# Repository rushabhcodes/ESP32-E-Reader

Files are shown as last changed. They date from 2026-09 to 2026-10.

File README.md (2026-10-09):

# ESP32 E-Reader Rev. B

A four-layer, battery-powered e-reader PCB built around the ESP32-C3 and a
high-resolution four-color e-paper display. This repository contains the
[tscircuit](https://tscircuit.com/) implementation of the Rev. B hardware,
including the schematic, PCB layout, component data, and fabrication export
workflow.

## At a glance

| Specification | Current design |
| --- | --- |
| Enclosure outside | 68.0 × 111.0 × **16.8 mm**; prototype CAD, not a measured print |
| PCB | 62.5 × 95.08 × 1.6 mm; four copper layers |
| Display | EastRising ER-EPD3.97-1RY, raw display only; 480 × 800, four colors, no frontlight |
| Processor | ESP32-C3-WROOM-02U-N4; 4 MB flash, Wi-Fi, Bluetooth LE, external antenna |
| Storage | MicroSD over SPI |
| Battery | Protected 1-cell LiPo, 3.7 V nominal; modeled around 2000 mAh SparkFun PRT-13855 |
| Battery envelope | 49.2 × 68.8 × 5.6 mm nominal, excluding unverified lead and plug |
| USB | USB-C for charging and native ESP32-C3 USB data |
| Input | Four recessed navigation buttons, wake, reset, main power switch |

This repository is the **hardware and printable enclosure prototype**. It
does not contain e-reader firmware. Battery runtime, display cable fit, and
final printed fit have not been measured on an assembled device.

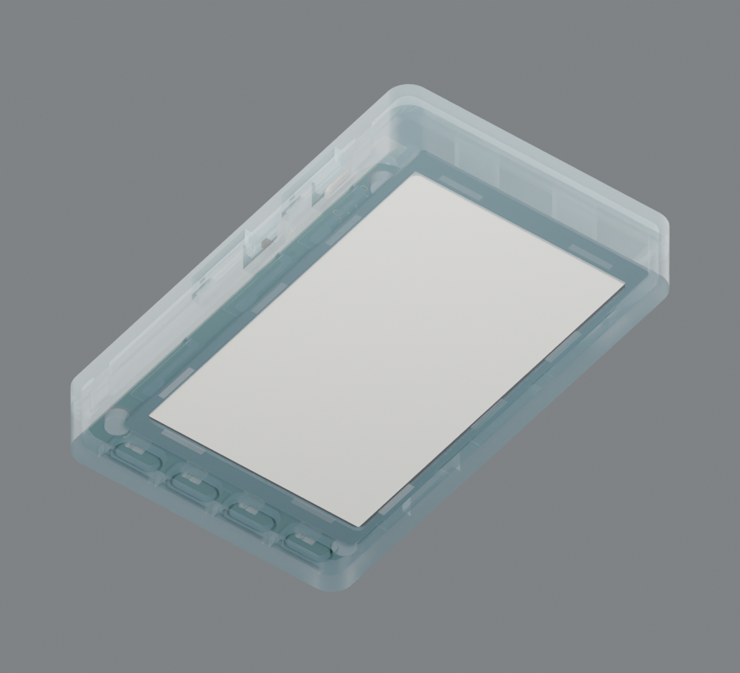
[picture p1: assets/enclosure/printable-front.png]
Front of the dimensioned e-reader print prototype


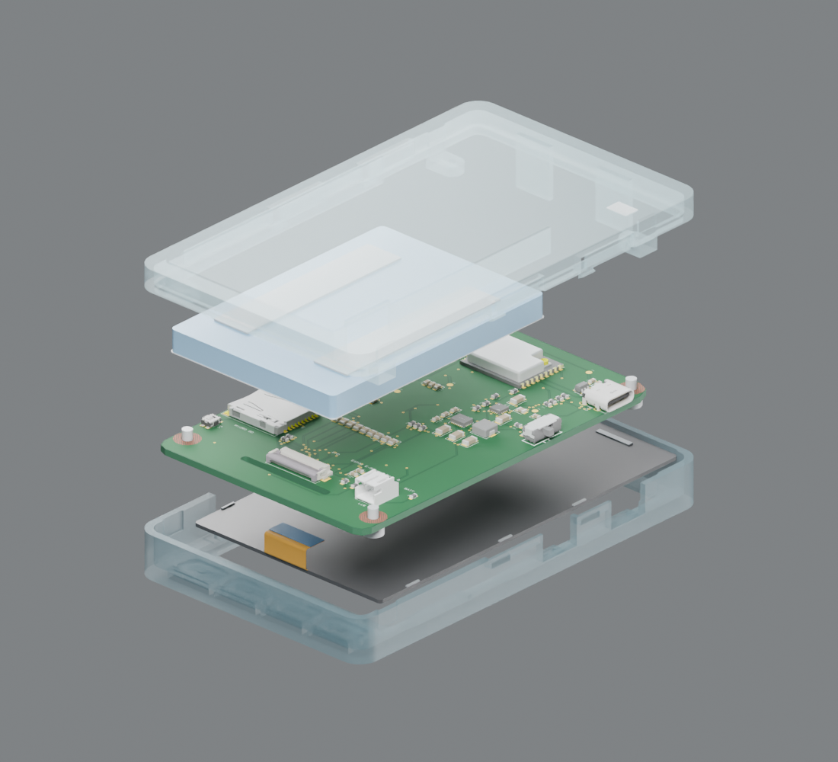
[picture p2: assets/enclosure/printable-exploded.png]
Exploded view of the screen, PCB, battery and rear cover


## Display

The selected panel is the [EastRising ER-EPD3.97-1RY](https://www.buydisplay.com/3-97-inch-quad-color-e-paper-screen-e-ink-display-480x800),
identified by the user on 6 October 2026. Its [datasheet](https://www.buydisplay.com/download/manual/ER-EPD3.97-1_Datasheet.pdf)
(Rev. 1.0, 18 August 2026) specifies an SSD2677 controller, 480 × 800 pixels,
and a 56.24 × 96.62 mm panel, matching the existing display envelope.

J2 remains the Hirose FH12-24S-0.5SH(55), with 24 positions at 0.50 mm
pitch. At the user's direction, the supplier product listing is authoritative
for connector pitch in this revision. No adapter is used. The conflicting
0.80 mm drawing is recorded as a supplier documentation discrepancy, rather
than the design basis. Connector fit remains a listing-based assumption;
contact side, stiffener thickness and cable fold still need a sample fit.

The PDF pin assignments match J2's existing functions. Pins 6 (TSCL) and
7 (TSDA) are connected to GND to give the unused sensor inputs defined low
levels, as required by page 7. Pin 8 is also low for four-wire SPI.

The display uses the same connection style as the
[Linux Game Boy Advance reference](https://tscircuit.com/ShiboSoftwareDev/linux-gameboy-advance#3d):
a folded flat ribbon entering a horizontal, bottom-contact ZIF socket.
The reader uses the [24-pin Hirose FH12](https://www.hirose.com/en/product/p/CL0586-0521-0-55)
for its e-paper pinout. Open the flip latch, insert the tail straight with its
exposed contacts facing the PCB, then close the latch.

J2 and the 26 × 2 mm rounded ribbon slot share X = 0 mm. J2 is now at
Y = −32.34 mm and the slot at Y = −38.41 mm, shortening the path from the
lower panel edge. The installed model has two 0.6 mm-radius quarter bends
and an approximately 11.316 mm centerline, within the drawing's
11.27 ± 0.30 mm extension below the glass. It passes through the slot and
shows 24 bottom-facing contacts and a nominal 0.3 mm reinforced insertion tip.
The panel remains 56.24 × 96.62 × 0.9 mm at Y = 10.5 mm, Z −4.65…−3.75 mm;
the model now subtracts J2's 0.8 mm anchor height to align with the case rebate.

The [connection dimensions](assets/enclosure/display-connection.json) and
[installed ribbon preview](assets/enclosure/display-ribbon-connection.png)
describe nominal installation geometry, not OEM flex CAD. Its 12.5 mm tip
width follows the user-selected 24-pin, 0.5 mm listing specification; it does
not reproduce the conflicting PDF's 19.6 mm, 0.8 mm tip. The delivered tail's
width, contact face, reinforcement and allowable bend radius need a physical
sample. Do not force a mismatched ribbon into the socket.

> [!IMPORTANT]
> Do not select a panel based only on the “4.2-inch” description or the 24-pin
> connector. Many e-paper panels use similar FPCs but have different pinouts,
> resolutions, controllers, dimensions, and voltage requirements. The PCB and
> firmware must match the **EastRising ER-EPD3.97-1RY** pinout.
> J2 selection uses the supplier listing's 24-pin, 0.50 mm specification.

## Hardware overview

| Function | Implementation |
| --- | --- |
| MCU | ESP32-C3-WROOM-02U-N4, 4 MB flash, Wi-Fi and Bluetooth LE |
| Display | EastRising ER-EPD3.97-1RY raw 480 × 800 four-color panel |
| Storage | MicroSD card over shared SPI |
| USB | USB-C power, native USB data, CC resistors, and USB ESD protection |
| Battery | Single-cell LiPo through a 2-pin JST-PH connector |
| Charging | BQ24074 power-path LiPo charger, 500 mA USB input limit |
| Battery protection | DW01A with FS8205A dual MOSFET |
| Logic supply | TPS63021 fixed 3.3 V buck-boost converter |
| Controls | Back, Confirm, Left, Right, Wake, Reset/Enable, and main power switch |
| Board | 62.5 × 95.08 mm, 1.6 mm thick, four copper layers |

### Parts and supplies for one prototype

| Item | Selection / requirement |
| --- | --- |
| U4 microcontroller | ESP32-C3-WROOM-02U-N4 with external U.FL antenna |
| Display | EastRising ER-EPD3.97-1RY, raw display only |
| External antenna | Taoglas FXP75.07.0045B, 45 mm cable; rear-cover adhesive mount |
| J2 display connector | Hirose FH12-24S-0.5SH(55), 24 positions at 0.5 mm pitch |
| J4 MicroSD socket | Hirose DM3AT-SF-PEJM5 |
| J1 USB-C receptacle | GCT USB4105-GF-A |
| BT1 battery header | JST S2B-PH-K-S(LF)(SN), 2-pin, 2.0 mm pitch, side entry |
| Battery | Protected 3.7 V nominal single-cell pack; modeled PRT-13855, 2000 mAh, 49.2 × 68.8 × 5.6 mm |
| Navigation switches | 4 × Alps Alpine SKRPACE010, bottom-side assembly |
| Other controls | 2 × Panasonic EVQP7C01P (S1/S2); 1 × C&K JS102011SAQN (SW7) |
| Printed parts | Two: front chassis with integral keys, screen clips and latch receivers; transparent snap-fit rear cover with PCB supports and battery guides |
| Assembly supplies | 4 M2.5 × 4 mm internal PCB screws (head ≤5 mm diameter, ≤2.5 mm high), display-border pads, 0.2 mm insulating battery liner and two 0.5 mm nonconductive adhesive strips; zero cover screws |

The [source component list and LCSC/JLCPCB mappings](design-data.ts) and the
[generated BOM](#fabrication-files) cover the remaining passives, charger,
protection devices, ESD device, and e-paper bias circuit. The USB-C body is
checked against the printable case using the local GCT manufacturer OBJ;
the antenna cable and mating plug remain unmodeled. The display fold is nominal CAD. Confirm the delivered display tail, battery plug polarity,
antenna cable path, and screw fit before assembly.

The four navigation buttons share one ESP32 ADC input through a resistor
ladder. The e-paper display and MicroSD card share the SPI clock and MOSI lines
while using independent chip-select signals. USB D+ and D− connect directly to
the ESP32-C3's native USB pins.

The four front navigation controls use the same **Alps Alpine SKRPACE010**
bottom-side tactile switch listed in the [original reader's
BOM](https://github.com/IS7V4N/ESP32_E-Reader). Each switch is 4.2 × 3.2 ×
2.5 mm, with 0.2 mm travel and 2.55 N operating force according to the
[manufacturer](https://tech.alpsalpine.com/e/products/category/tact-switch/sub/02/series/skrp/).
They sit on 14 mm centers within the 62.5 mm board width. Moving the row 4 mm
closer to the display removes 5 mm from the lower PCB edge while keeping about
2 mm between the panel outline and the button openings. Four slim key caps and independent PETG leaf arms are integral to the front
chassis. This requires bottom-side switch assembly. Each key has a nominal
0.04 mm rest gap and 0.25 mm total stroke, giving about 0.21 mm switch
compression. Force, return and print fit need a physical prototype. Check the actual
display ribbon width and fold radius against the 26 mm FPC slot before ordering
the PCB.

## Dimensioned enclosure print prototype

The redesigned Rev. E enclosure uses **two printed parts** in a
**68.0 × 111.0 × 16.8 mm** envelope, 1.2 mm (6.7%) thinner than Rev. D.
Moving the same battery toward the button end avoids stacking it over the
ESP32 module. The front chassis combines the screen
ledge, six releasable padded border clips and four independently moving keys.
The transparent rear cover combines the PCB cantilever supports, battery guides,
four integral snap leaves and two extra supports for the upper screen border.

The PCB fastens to the rear cover from its display-facing underside. The
front chassis therefore has a clear path for screen installation. Four side
snap hooks engage matching receivers in the front chassis. Recessed side
windows allow releasing them with a plastic pick. Four M2.5 screws retain
the PCB; the cover uses no screws. The selected protected
[SparkFun PRT-13855 pack](https://www.sparkfun.com/lithium-ion-battery-2ah.html)
has **49.2 × 68.8 × 5.6 mm nominal dimensions**. It bonds to the inside rear
cover with two nonconductive foam adhesive strips; a thin insulating liner
covers its PCB-facing surface. No separate battery tray needs printing.
The battery is now centered at X −6.0, Y −8.5 mm and lowered from Z 4.9 to
Z 3.7. The rear wall remains 1.2 mm thick. The screen's padded ledge, six clips
and two upper supports retain their original seating positions.
Print both Rev. E shells as a pair. The battery loads through the open upper
end of its guides and slides 6.5 mm toward the lower stop before fitting the PCB.

| Thickness contribution | mm |
| --- | ---: |
| Front outer face to PCB center | 5.8 |
| PCB center to battery base | 3.7 |
| Nominal battery thickness | 5.6 |
| Battery mounting adhesive | 0.5 |
| Rear cover | 1.2 |
| **Modeled outside thickness** | **16.8** |

The battery liner has 0.25 mm nominal clearance above the lower PCB mounting
bosses and about 0.59 mm above L1. The shifted battery's liner clears the
ESP32 module by 1.63 mm in Y. These are CAD measurements; actual pack thickness,
swelling allowance, wires and printed tolerances need a prototype check.

The actual CAD materials use alpha blending: 0.38 opacity for the front,
0.22 for the rear. The hosted viewer and native export use 0.5 opacity through
the explicit translucency flags. This lets you see the components inside. Clear PETG FDM
prints are normally translucent; the CAD appearance does not predict glass-like
clarity. The design assumes a 0.4 mm nozzle and PETG flexures. Physical fit,
clip force, key fatigue, battery retention and cable routing need a prototype.

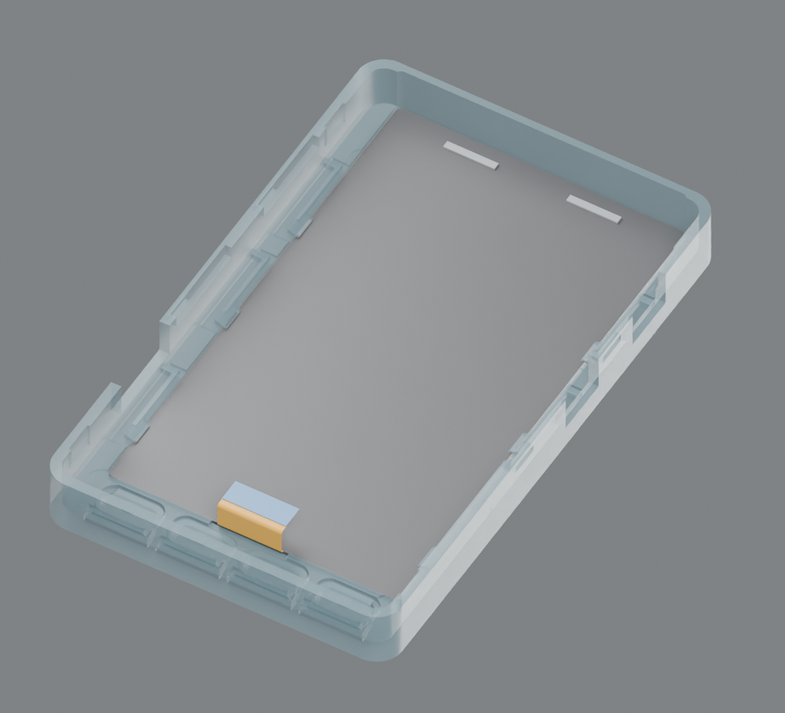
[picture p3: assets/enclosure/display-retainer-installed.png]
Display held on padded border ledges and integral side clips


The [print ZIP](assets/enclosure/esp32-reader-printable-stls.zip) contains exactly
**two bed-oriented STLs**, the [220 × 220 mm 3MF plate](assets/enclosure/reader-print-plate.3mf),
and the [print and assembly guide](assets/enclosure/PRINTING.md). Both parts
print flat, outside face on the bed. Use removable supports under the spring
leaves and projecting features, including supports that start on the model.
The open battery pocket leaves them accessible for removal.

The [component inventory](assets/enclosure/component-inventory.csv) records
PCB references, footprint sizes and model envelopes. `bun run export:assembly`
resolves the local CAD and writes `dist/index/assembly.glb`; missing OBJ/GLB
fetches fail the export. Supplier OBJ models are bundled for browser rendering.
The supplier STEP archives ([1](assets/components/supplier-step-models-1.zip), [2](assets/components/supplier-step-models-2.zip), [3](assets/components/supplier-step-models-3.zip), [4](assets/components/supplier-step-models-4.zip), [5](assets/components/supplier-step-models-5.zip)) preserve
original source models without loading large STEP duplicates in the preview.
Source URLs and hashes remain in `assets/components/sources.json`.

Four PCB mounting holes retain their original coordinates: the upper pair at
X ±27, Y 44.75 mm and the lower pair at X ±28, Y −40 mm. Each 2.7 mm hole has
a 3.2 mm copper keepout on every layer. The board seats at Z +0.8 on rear-cover
bosses and the M2.5 × 4 mm screws enter from the underside. PCB geometry,
component placement, electrical connections and routed copper remain unchanged.
Run `bun scripts/check-pcb-mounts.mjs` after the routed build to check drills,
board edges and copper. The enclosure check verifies screwdriver access with
the front chassis removed.

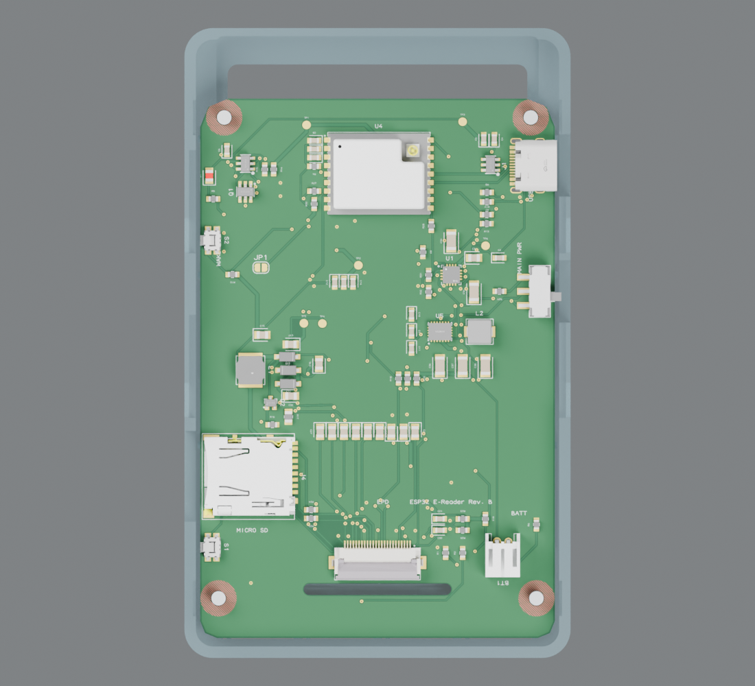
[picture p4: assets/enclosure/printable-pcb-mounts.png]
PCB mounting points in the two-part enclosure


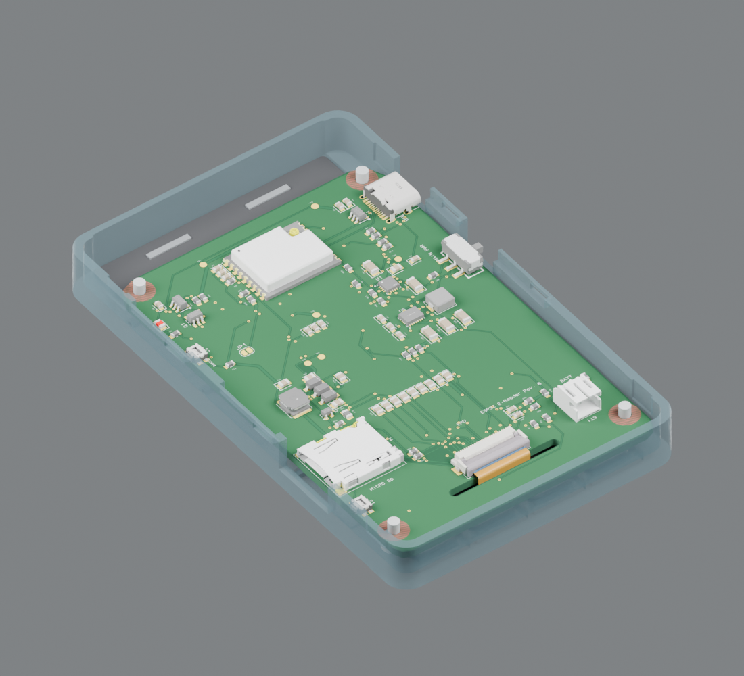
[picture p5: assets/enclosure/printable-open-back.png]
Electronics with the rear cover removed


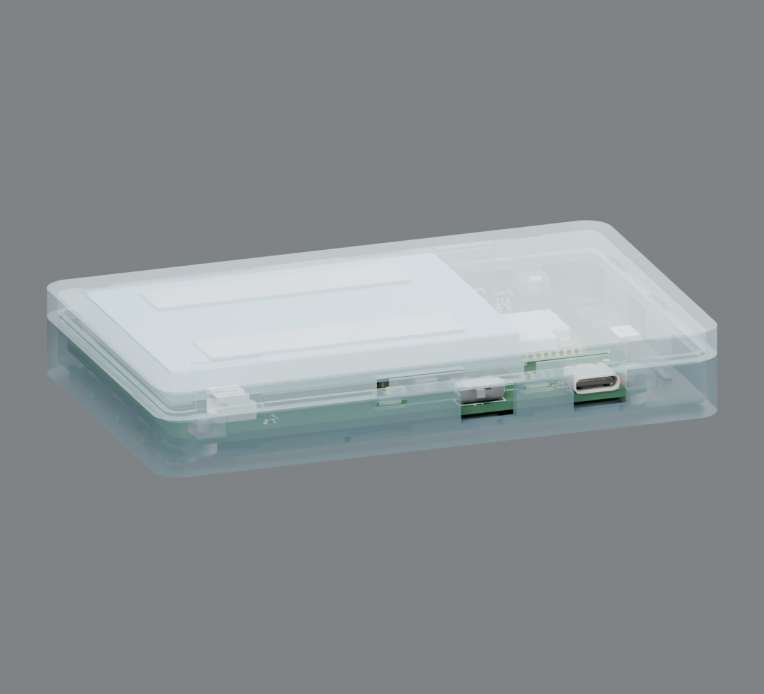
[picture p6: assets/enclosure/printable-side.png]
Transparent side view of the 16.8 mm enclosure


The front navigation switches remain the low-profile SKRPACE010 parts. The
power switch is accessible through a side slot; a coupled thumb slider is not
included. Display flex, battery plug polarity, actual lead lengths and antenna
coax routing still require sample verification before assembly.

## Board construction

The layer arrangement is:

```text
Top      — components and signals
Inner 1  — GND plane
Inner 2  — 3.3 V plane
Bottom   — components and signals
```

Ground fills are also present on the top and bottom layers. U4 is the
external-antenna ESP32-C3-WROOM-02U variant. Its antenna cable leads to the
Taoglas FXP75 film modeled at X = 25, Y = 44 mm under the plastic rear cover.
The old PCB-antenna copper keepout has been removed.
The design requests 0.2 mm ordinary signal traces, 0.5 mm battery/USB/3.3 V
routes, and 0.4–0.6 mm e-paper charge-pump routes. Fine-pitch escapes may be narrowed by the autorouter; inspect the routed
artifact rather than assuming every segment uses the requested net width. Vias request 0.30/0.60 mm drill/pad diameters, with a 0.15 mm radial
annulus. Routing requires 0.20 mm hole-to-trace and via-hole-to-via-hole
clearance, 0.45 mm plated-hole-to-hole clearance, and 0.30 mm board-edge
clearance. Via-in-pad routing is disabled.

PCB layout

### JLCPCB fabrication settings

Use four-layer FR-4, 1.6 mm thickness, standard copper (1 oz outer / 0.5 oz
inner), green solder mask and standard routing tolerances. The board fits
inside 100 × 100 mm. Choose ordinary through vias and tenting, with no
blind/buried vias or filled/capped via-in-pad service. Check the live quote;
these settings target standard fabrication, not a guaranteed price.

[JLCPCB's manufacturing capabilities](https://jlcpcb.com/capabilities/pcb-capabilities/)
(accessed 6 October 2026) state that 0.20/0.25 mm holes with pads below
0.45 mm incur extra charges. The former 0.20/0.42 mm vias met that condition;
the new 0.30/0.60 mm target avoids it. The 2.7 mm mounting holes and 2 mm
ribbon slot exceed the 0.5 mm NPTH and 1 mm non-plated slot minima.
Select 0.30 mm as the order's minimum via drill only after checking the
exported drill file.

For assembly, compare lead-free HASL with ENIG in the quote and assembly
preview; J2's 0.5 mm pitch and the QFN parts benefit from ENIG's flat surface.
Double-sided assembly, extended parts and surface finish can affect cost
separately from via drilling. Retain the four layers for the present routing
and planes; a two-layer cost reduction would require a separate redesign.

## Repository layout

```text
.
├── index.circuit.tsx       # Board outline, planes, keepouts, and net routing
├── circuit-sections.tsx    # Functional schematic sections and components
├── design-data.ts          # Parts, placement, sourcing, nets, and trace widths
├── schematic-layout.ts     # Explicit positions for all 94 parts on five sheets
├── imports/                # Imported component footprints and models
├── __snapshots__/          # PCB, schematic, and 3D reference renders
├── assets/enclosure/       # Printable STLs, assembly GLBs, guide, and renders
├── scripts/                # Enclosure generation and clearance checks
├── tscircuit.config.json   # tscircuit project configuration
└── package.json            # Build, validation, and export commands
```

Placement, board geometry, and electrical intent are transcribed from the Rev. B KiCad
design; PCB routing is generated from the netlist by tscircuit's local
autorouter.

The schematic groups parts by function, with dedicated power, display,
storage, and control sections. `functional-schematic-symbols.tsx` arranges
chip pins for readable signal flow while retaining physical pin identities.
The controls sheet shows the navigation buttons on one ADC bus with their
resistors below and names beside each key. The SKRPACE010 symbol explicitly
maps its active contacts to physical pins 1 and 4. After building, run
`bun scripts/check-controls-schematic.mjs` to verify the visible bus and
resistor connections, including terminals missed by ordinary style checks.
The design reuses the verified copper from release 1.0.54, rechecked with the
four mounting holes in release 1.0.57, through
`verified-pcb-routes.json`. The cache compares the complete routing geometry,
connectivity, keepouts, widths, and rules; physical changes use the autorouter
again. Check this guard with `bun scripts/check-routing-cache.mjs`.

## Getting started

Install [Bun](https://bun.sh/) and then install the project dependencies:

```sh
bun install
```

Open the interactive tscircuit development view:

```sh
bun run dev
```

Type-check and build the design:

```sh
bun run typecheck
bun run build:pcb
```

`build:pcb` also generates a PCB preview image. For a longer release build with
an increased autorouter timeout, use:

```sh
bun run build:release
```

Cloud builds use a 40-minute worker limit from `tscircuit.config.json`. The
default 10-minute limit stopped release 1.0.51 during PCB routing, before the
schematic, PCB, and 3D artifacts could be generated.

The cloud prebuild also copies local GLB, OBJ, and STEP models into `dist` at
the paths referenced by circuit JSON, so the hosted 3D view can load them.

## Validation

Run the checks in this order so connectivity errors are caught before layout
and routing issues:

```sh
bunx tsci check netlist index.circuit.tsx
bunx tsci check schematic-placement index.circuit.tsx
bunx tsci check placement index.circuit.tsx
bunx tsci check trace-length index.circuit.tsx
bunx tsci check routing-difficulty index.circuit.tsx
bun run build:release
bunx tsci check shorts dist/index/circuit.json
```

Update the checked-in schematic, PCB, and 3D snapshots with:

```sh
bun run snapshot:update
```

The current cloud-style build completes with 228 routed traces, zero DRC
errors, and no Gerber-derived shorts across all four layers. Its 178 vias are
all 0.30/0.60 mm ordinary through vias. Netlist, schematic placement, PCB
placement, and TypeScript checks pass. Schematic style analysis reports no
issues across all five sheets. Buried-layer keepouts prevent through vias from
overlapping the USB-C contacts, U3 contacts, and C19/C20 ground pads.

The source and regenerated fabrication export ground J2 pins 6 and 7. The export guard
rejects artifacts without both sensor pins grounded. Connector pitch follows
the supplier listing at the user's direction. Physical screen-tail, battery
lead, button travel and printed-fit checks remain necessary.

## Printable enclosure

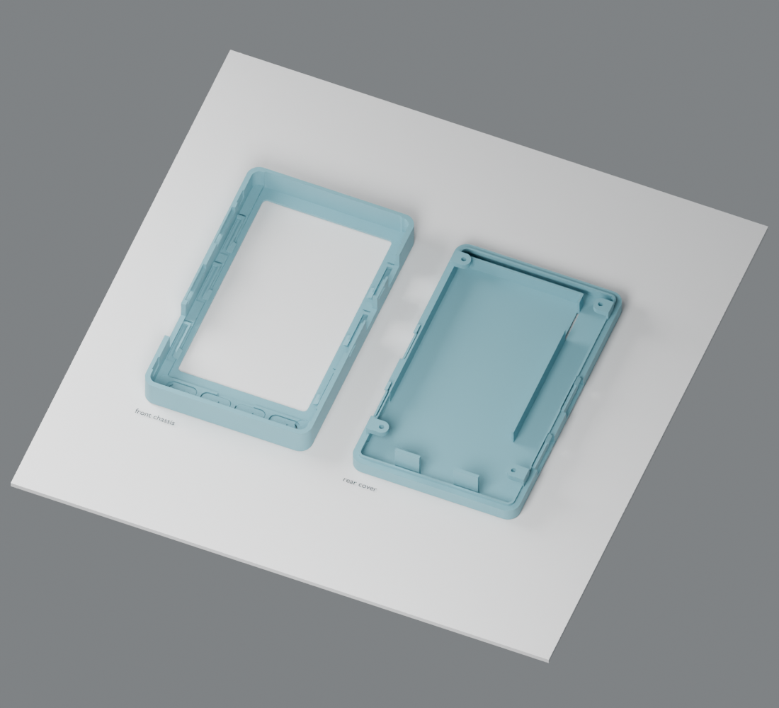
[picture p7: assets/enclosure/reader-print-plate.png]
Two parts arranged for printing on a 220 mm bed


The [print package](assets/enclosure/esp32-reader-printable-stls.zip)
contains two bed-oriented STLs, a geometry-only
[3MF plate](assets/enclosure/reader-print-plate.3mf), and the
[print instructions](assets/enclosure/PRINTING.md). The separate
[STLs](assets/enclosure/print/) are also available. Files marked `DO-NOT-PRINT`
are inspection gauges. The integral keys, cover snaps and screen clips require PETG and removable
supports beneath their projecting leaves. Choose your actual printer and filament
preset before slicing; no printer-specific G-code is supplied.

To regenerate the meshes from source, install Blender and run:

```sh
blender --background --python-exit-code 1 --python scripts/generate-printable-enclosure.py
```

The generator updates the STL files, matching GLBs for the tscircuit
assembly, mesh checks, and ZIP package. The [print guide](assets/enclosure/PRINTING.md)
also gives the component-clearance and preview-render commands.

After the release checks pass, commit the source and publish with
`bun run push:release`, then push the commit to GitHub. This command runs
`tsci push` from the committed runtime files, with original STEP
models in their small ZIP archives, because direct `tsci push`
does not honor `.gitignore` and can upload local check fixtures and caches.
Prebuild restores downloads and PNG previews from tracked STEP/STL/JSON sources
because the Git importer omits ZIP and image files. Re-rendering also refreshes
the checksummed preview restore sources.

## Fabrication files

Generate the manufacturing archive with:

```sh
bun run build:release
bun run export:gerbers
```

`export:gerbers` uses the just-built `dist/index/circuit.json`, so it does not
routinely rerun the autorouter. The output is written to
`dist/esp32-e-reader-gerbers.zip` and includes the
four copper layers, solder mask, paste, silkscreen, fabrication and edge-cut
Gerbers, plated/non-plated drill files, BOM, and pick-and-place CSV files.
All BOM rows have JLCPCB part numbers, including the four SKRPACE010
navigation switches (C139797). U1, U2, U3, U4, U5, L2, SW2, SW3, SW4, and
SW6 use imported supplier footprints for assembly placement. `export:gerbers`
checks the BOM, critical placement rows, absence of build errors, centered J2,
through-via geometry, and the actual minimum plated drill before accepting
the archive.

The exporter still warns about SW7 because its three straight-line pads do not
give the pin-1 detector a corner. SW7 uses the exact C221660 supplier footprint;
the [C&K terminal drawing](https://www.ckswitches.com/media/1434/slides.pdf)
shows terminal 1 at the left end of that row. With the footprint rotated 90° on
the board, pad 1 is the bottom pad. The export check requires SW7 on the top
side at 90°. Confirm the SW7 orientation in the assembler's placement preview.

> [!CAUTION]
> This is a prototype hardware design, not a certified consumer product. Review the
> schematic, battery polarity, component voltage ratings, PCB clearances, BOM,
> and fabrication outputs before ordering or powering a board. E-paper bias
> rails generate voltages well above the 3.3 V logic rail.

### Release checks requiring physical parts

The design changes below address the known schematic and drawing-level
blockers. **Do not release a full assembly order yet.** First mate a sample selected panel with J2 and confirm the FPC fold through the slot, pin 1,
contact side, and latch closure. Fit the exact protected battery and its keyed
plug in a printed case, then inspect the USB-C body, antenna cable, and lid
closure. On a prototype PCB, measure charge termination while reading,
3.3 V ripple and transient response at low battery, and Wi-Fi performance
with the lid and battery installed. The antenna choice may also require
regional RF compliance testing because its published 2.5 dBi peak gain
exceeds the module datasheet's certified-antenna gain limits. Programming,
screen refresh, SD I/O, and low-battery shutdown still need firmware bring-up.

## Power, charging, and bring-up

- U1 is a [BQ24074 power-path charger](https://www.ti.com/lit/ds/symlink/bq24074.pdf).
  Its BAT pins charge the cell while its separate OUT pins feed the reader.
  EN1 = high and EN2 = low select the 500 mA USB input-current limit.
  R9 = 2.5 kΩ sets about **356 mA** nominal fast-charge current
  (890 AΩ / 2500 Ω). Dynamic power management reduces charging when the
  system uses more of the USB budget. R31 = 10 kΩ holds TS in its valid
  no-thermistor range; the two-wire pack provides no cell temperature signal.
  Charge only within the pack's specified temperature range, and verify the
  pack's allowed rate. Confirm actual current, termination, and thermal
  behavior with and without system load on a prototype. Battery-free operation
  also needs a load test: the 500 mA USB input budget may not cover simultaneous
  Wi-Fi, SD-card, and display peaks.
- SW7 drives U5's EN pin from `SYS_OUT`; it does not carry load current.
  This lets the regulator turn on from either a connected battery or USB.
  S2 remains a firmware-controlled wake button.
- U5 is the [TPS63021 fixed 3.3 V buck-boost
  converter](https://www.ti.com/lit/ds/symlink/tps63021.pdf). L2 is a
  shielded 1.5 µH inductor rated 5 A, with two 10 µF input capacitors and
  three nominal 22 µF/25 V output capacitors close to U5. The converter
  operates from the charger OUT node whether USB is present or not. Check
  the effective ceramic capacitance under DC bias, the switching loop, rail
  ripple, and transient response at the actual Wi-Fi, SD, and display loads.
- R30 pulls ESP32-C3 GPIO8 high on the MCU side of the 20 Ω SPI-clock series
  resistor R27. Closing JP1 pulls GPIO9 low for ROM download mode; GPIO8 must
  remain high through reset. Test programming with the display and SD card
  connected, then open JP1 and confirm normal boot. See the
  [ESP32-C3 boot-mode table](https://docs.espressif.com/projects/esp-hardware-design-guidelines/en/latest/esp32c3/schematic-checklist.html).
- Measure battery voltage at TP1 and 3.3 V at TP2 during low-state-of-charge
  Wi-Fi transmit, SD writes, and display refresh. Set a firmware low-battery
  shutdown threshold with margin above the battery protection cutoff. This
  repository does not implement that firmware.

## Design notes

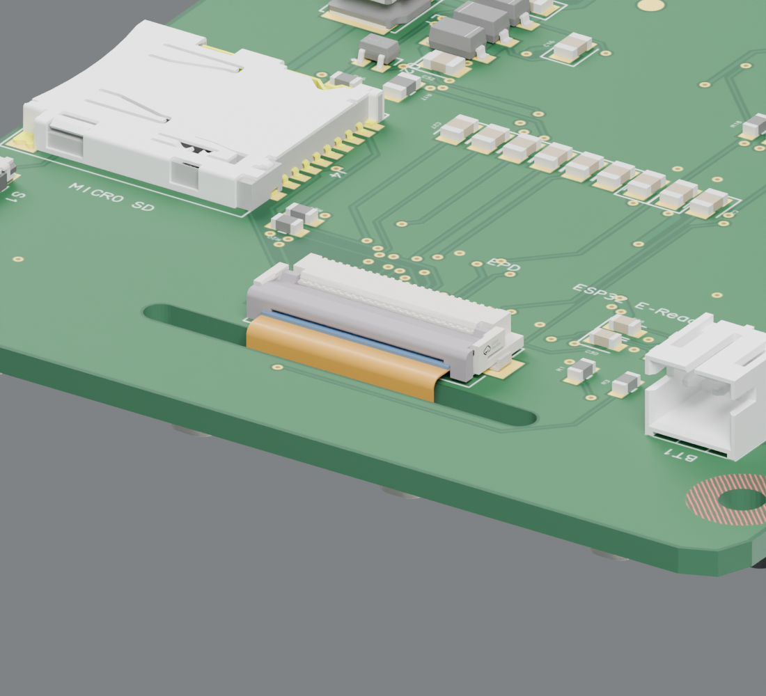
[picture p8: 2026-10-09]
assets/enclosure/display-ribbon-connection.png

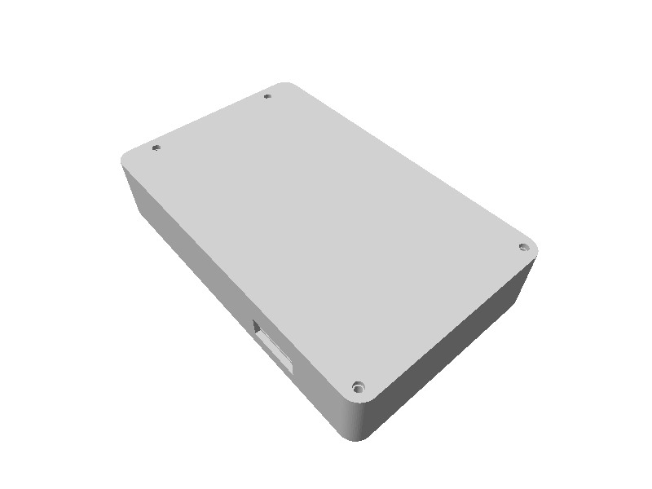
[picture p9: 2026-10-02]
__snapshots__/index.circuit-3d.snap.png

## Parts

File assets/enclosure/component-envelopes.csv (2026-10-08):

model_name | x_min_mm | x_max_mm | y_min_mm | y_max_mm | z_min_mm | z_max_mm
BT1 | 19.05 | 25.05 | -36.275 | -28.575 | -2.7 | 5.85
C1 | -11.95 | -10.35 | 37.255 | 38.105 | 0.8 | 1.4
C10 | 5.575 | 6.425 | 9.2 | 10.8 | 0.8 | 1.4
C11 | 5.575 | 6.425 | 3.2 | 4.8 | 0.8 | 1.4
C12 | -7.955 | -7.105 | 14.84 | 16.44 | 0.8 | 1.4
C13 | -6.355 | -5.505 | 14.84 | 16.44 | 0.8 | 1.4
C14 | -4.735 | -3.885 | 14.84 | 16.44 | 0.8 | 1.4
C15 | -21.282 | -19.282 | 5.795 | 7.045 | 0.8 | 1.35
C16 | -10.925 | -9.675 | 0.31 | 2.31 | 0.8 | 1.35
C17 | -16.28 | -14.28 | 4.125 | 5.375 | 0.8 | 1.35
C19 | 3.975 | 5.225 | -11.658 | -9.658 | 0.8 | 1.35
C2 | 20.7 | 22.3 | 19.575 | 20.425 | 0.8 | 1.4
C20 | 1.825 | 3.075 | -11.658 | -9.658 | 0.8 | 1.35
C21 | -0.225 | 1.025 | -11.658 | -9.658 | 0.8 | 1.35
C22 | -4.425 | -3.175 | -11.658 | -9.658 | 0.8 | 1.35
C23 | -8.625 | -7.375 | -11.658 | -9.658 | 0.8 | 1.35
C24 | 10.2 | 11.8 | -26.425 | -25.575 | 0.8 | 1.4
C25 | -2.325 | -1.075 | -11.658 | -9.658 | 0.8 | 1.35
C27 | -10.725 | -9.475 | -11.658 | -9.658 | 0.8 | 1.35
C28 | -6.525 | -5.275 | -11.658 | -9.658 | 0.8 | 1.35
C29 | 5.995 | 7.245 | -11.658 | -9.658 | 0.8 | 1.35
C3 | 16.0 | 18.0 | 19.375 | 20.625 | 0.8 | 1.35
C30 | 10.2 | 11.8 | -28.425 | -27.575 | 0.8 | 1.4
C32 | -16.24 | -14.24 | -4.965 | -3.715 | 0.8 | 1.35
C34 | 12.2 | 13.8 | 21.4 | 24.6 | 0.8 | 1.7
C35 | 16.2 | 17.8 | 12.4 | 15.6 | 0.8 | 1.7
C36 | 10.2 | 11.8 | -0.6 | 2.6 | 0.8 | 1.7
C37 | 14.2 | 15.8 | -0.6 | 2.6 | 0.8 | 1.7
C38 | 18.2 | 19.8 | -0.6 | 2.6 | 0.8 | 1.7
C4 | 20.15 | 21.0 | 40.167 | 41.767 | 0.8 | 1.4
C5 | 18.3 | 19.15 | 40.167 | 41.767 | 0.8 | 1.4
C6 | -26.951 | -26.101 | 38.212 | 39.812 | 0.8 | 1.4
C7 | -11.95 | -10.35 | 38.755 | 39.605 | 0.8 | 1.4
C8 | -11.95 | -10.35 | 40.265 | 41.115 | 0.8 | 1.4
C9 | 5.575 | 6.425 | 6.2 | 7.8 | 0.8 | 1.4
D1 | -30.249 | -28.999 | 33.475 | 35.475 | 0.8 | 1.35
D2 | -17.675 | -13.825 | -3.04 | -1.34 | 0.8 | 2.25
D3 | -17.663 | -13.812 | -0.66 | 1.04 | 0.8 | 2.25
D4 | -17.825 | -13.975 | 1.72 | 3.42 | 0.8 | 2.25
J1 | 24.04 | 31.595 | 31.79 | 40.73 | -0.2 | 3.97
J2 | -8.05 | 8.05 | -36.729 | -30.329 | 0.8 | 2.9
J4 | -30.487 | -14.527 | -25.42 | -11.57 | 0.8 | 2.69
L1 | -24.878 | -19.878 | -2.307 | 2.713 | 0.8 | 2.91
L2 | 15.7 | 20.3 | 4.9 | 9.1 | 0.8 | 2.8
Q1 | -24.724 | -21.824 | 30.24 | 33.052 | 0.8 | 2.449
Q2 | -19.81 | -17.81 | -6.61 | -4.51 | 0.8 | 1.975
R1 | 11.575 | 12.425 | -32.8 | -31.2 | 0.8 | 1.4
R10 | -26.342 | -24.743 | 16.645 | 17.495 | 0.8 | 1.4
R11 | 18.575 | 19.425 | -26.8 | -25.2 | 0.8 | 1.4
R12 | 18.458 | 20.057 | 27.205 | 28.055 | 0.8 | 1.4
R13 | 18.44 | 20.04 | 25.605 | 26.455 | 0.8 | 1.4
R14 | -18.721 | -17.871 | 34.808 | 36.408 | 0.8 | 1.4
R15 | -20.296 | -19.446 | 34.808 | 36.408 | 0.8 | 1.4
R16 | -19.307 | -17.708 | -9.835 | -8.985 | 0.8 | 1.4
R17 | -16.305 | -15.055 | -9.02 | -7.02 | 0.8 | 1.35
R18 | 3.285 | 4.135 | -2.07 | -0.47 | 0.8 | 1.4
R19 | 6.465 | 7.315 | -2.07 | -0.47 | 0.8 | 1.4
R20 | -12.5 | -10.9 | -26.335 | -25.485 | 0.8 | 1.4
R21 | 4.845 | 5.695 | -2.07 | -0.47 | 0.8 | 1.4
R23 | 14.2 | 15.8 | -26.425 | -25.575 | 0.8 | 1.4
R24 | -12.5 | -10.9 | -24.811 | -23.961 | 0.8 | 1.4
R25 | 14.2 | 15.8 | -28.425 | -27.575 | 0.8 | 1.4
R27 | -11.95 | -10.35 | 31.345 | 32.195 | 0.8 | 1.4
R28 | 9.05 | 9.9 | 24.83 | 26.43 | 0.8 | 1.4
R29 | 20.7 | 22.3 | 13.675 | 14.525 | 0.8 | 1.4
R3 | 14.575 | 15.425 | -32.8 | -31.2 | 0.8 | 1.4
R30 | -11.575 | -10.725 | 28.7 | 30.3 | 0.8 | 1.4
R31 | 8.575 | 9.425 | 16.2 | 17.8 | 0.8 | 1.4
R32 | 8.575 | 9.425 | 13.2 | 14.8 | 0.8 | 1.4
R4 | -11.96 | -10.36 | 35.715 | 36.565 | 0.8 | 1.4
R5 | -29.72 | -28.12 | 29.965 | 30.815 | 0.8 | 1.4
R6 | 27.575 | 28.425 | -27.8 | -26.2 | 0.8 | 1.4
R7 | 18.483 | 20.082 | 29.435 | 30.285 | 0.8 | 1.4
R8 | 18.483 | 20.082 | 31.115 | 31.965 | 0.8 | 1.4
R9 | 7.575 | 8.425 | 20.2 | 21.8 | 0.8 | 1.4
S1 | -31.211 | -27.661 | -33.357 | -28.657 | 0.3 | 2.15
S2 | -31.161 | -27.611 | 20.723 | 25.423 | 0.3 | 2.15
SW2 | 4.651 | 9.349 | -44.1 | -40.9 | -3.31 | -0.8
SW3 | -9.349 | -4.651 | -44.1 | -40.9 | -3.31 | -0.8
SW4 | 18.651 | 23.349 | -44.1 | -40.9 | -3.31 | -0.8
SW6 | -23.349 | -18.651 | -44.1 | -40.9 | -3.31 | -0.8
SW7 | 24.846 | 32.376 | 9.605 | 18.605 | 0.0 | 4.35
U1 | 11.49 | 14.51 | 15.49 | 18.51 | 0.8 | 1.56
U2 | 18.514 | 21.326 | 34.958 | 37.858 | 0.8 | 2.449
U3 | -24.656 | -21.843 | 35.174 | 38.074 | 0.8 | 2.449
U4 | -8.75 | 9.25 | 27.63 | 41.93 | 0.8 | 4.01
U5 | 8.99 | 13.01 | 5.49 | 8.51 | 0.8 | 1.81

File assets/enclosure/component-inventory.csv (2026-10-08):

refdes | pcb_x_mm | pcb_y_mm | side | pcb_footprint_width_mm | pcb_footprint_height_mm | model_width_mm | model_length_mm | model_z_min_mm | model_z_max_mm | source
BT1 | 22.025 | -30 | top | 3.45 | 1.5 | 6.0 | 7.7 | -2.7 | 5.85 | tsci tessellated model, nominal
C1 | -11.15 | 37.68 | top | 2.45 | 0.95 | 1.6 | 0.85 | 0.8 | 1.4 | tsci tessellated model, nominal
C10 | 6 | 10 | top | 0.95 | 2.45 | 0.85 | 1.6 | 0.8 | 1.4 | tsci tessellated model, nominal
C11 | 6 | 4 | top | 0.95 | 2.45 | 0.85 | 1.6 | 0.8 | 1.4 | tsci tessellated model, nominal
C12 | -7.53 | 15.64 | top | 0.95 | 2.45 | 0.85 | 1.6 | 0.8 | 1.4 | tsci tessellated model, nominal
C13 | -5.93 | 15.64 | top | 0.95 | 2.45 | 0.85 | 1.6 | 0.8 | 1.4 | tsci tessellated model, nominal
C14 | -4.31 | 15.64 | top | 0.95 | 2.45 | 0.85 | 1.6 | 0.8 | 1.4 | tsci tessellated model, nominal
C15 | -20.282 | 6.42 | top | 2.85 | 1.4 | 2.0 | 1.25 | 0.8 | 1.35 | tsci tessellated model, nominal
C16 | -10.3 | 1.31 | top | 1.4 | 2.85 | 1.25 | 2.0 | 0.8 | 1.35 | tsci tessellated model, nominal
C17 | -15.28 | 4.75 | top | 2.85 | 1.4 | 2.0 | 1.25 | 0.8 | 1.35 | tsci tessellated model, nominal
C19 | 4.6 | -10.657 | top | 1.4 | 2.85 | 1.25 | 2.0 | 0.8 | 1.35 | tsci tessellated model, nominal
C2 | 21.5 | 20 | top | 2.45 | 0.95 | 1.6 | 0.85 | 0.8 | 1.4 | tsci tessellated model, nominal
C20 | 2.45 | -10.657 | top | 1.4 | 2.85 | 1.25 | 2.0 | 0.8 | 1.35 | tsci tessellated model, nominal
C21 | 0.4 | -10.657 | top | 1.4 | 2.85 | 1.25 | 2.0 | 0.8 | 1.35 | tsci tessellated model, nominal
C22 | -3.8 | -10.657 | top | 1.4 | 2.85 | 1.25 | 2.0 | 0.8 | 1.35 | tsci tessellated model, nominal
C23 | -8 | -10.657 | top | 1.4 | 2.85 | 1.25 | 2.0 | 0.8 | 1.35 | tsci tessellated model, nominal
C24 | 11 | -26 | top | 2.45 | 0.95 | 1.6 | 0.85 | 0.8 | 1.4 | tsci tessellated model, nominal
C25 | -1.7 | -10.657 | top | 1.4 | 2.85 | 1.25 | 2.0 | 0.8 | 1.35 | tsci tessellated model, nominal
C27 | -10.1 | -10.657 | top | 1.4 | 2.85 | 1.25 | 2.0 | 0.8 | 1.35 | tsci tessellated model, nominal
C28 | -5.9 | -10.657 | top | 1.4 | 2.85 | 1.25 | 2.0 | 0.8 | 1.35 | tsci tessellated model, nominal
C29 | 6.62 | -10.657 | top | 1.4 | 2.85 | 1.25 | 2.0 | 0.8 | 1.35 | tsci tessellated model, nominal
C3 | 17 | 20 | top | 2.85 | 1.4 | 2.0 | 1.25 | 0.8 | 1.35 | tsci tessellated model, nominal
C30 | 11 | -28 | top | 2.45 | 0.95 | 1.6 | 0.85 | 0.8 | 1.4 | tsci tessellated model, nominal
C32 | -15.24 | -4.34 | top | 2.85 | 1.4 | 2.0 | 1.25 | 0.8 | 1.35 | tsci tessellated model, nominal
C34 | 13 | 23 | top | 1.75 | 4.05 | 1.6 | 3.2 | 0.8 | 1.7 | tsci tessellated model, nominal
C35 | 17 | 14 | top | 1.75 | 4.05 | 1.6 | 3.2 | 0.8 | 1.7 | tsci tessellated model, nominal
C36 | 11 | 1 | top | 1.75 | 4.05 | 1.6 | 3.2 | 0.8 | 1.7 | tsci tessellated model, nominal
C37 | 15 | 1 | top | 1.75 | 4.05 | 1.6 | 3.2 | 0.8 | 1.7 | tsci tessellated model, nominal
C38 | 19 | 1 | top | 1.75 | 4.05 | 1.6 | 3.2 | 0.8 | 1.7 | tsci tessellated model, nominal
C4 | 20.575 | 40.968 | top | 0.95 | 2.45 | 0.85 | 1.6 | 0.8 | 1.4 | tsci tessellated model, nominal
C5 | 18.725 | 40.968 | top | 0.95 | 2.45 | 0.85 | 1.6 | 0.8 | 1.4 | tsci tessellated model, nominal
C6 | -26.526 | 39.012 | top | 0.95 | 2.45 | 0.85 | 1.6 | 0.8 | 1.4 | tsci tessellated model, nominal
C7 | -11.15 | 39.18 | top | 2.45 | 0.95 | 1.6 | 0.85 | 0.8 | 1.4 | tsci tessellated model, nominal
C8 | -11.15 | 40.69 | top | 2.45 | 0.95 | 1.6 | 0.85 | 0.8 | 1.4 | tsci tessellated model, nominal
C9 | 6 | 7 | top | 0.95 | 2.45 | 0.85 | 1.6 | 0.8 | 1.4 | tsci tessellated model, nominal
D1 | -29.624 | 34.475 | top | 1.4 | 2.85 | 1.25 | 2.0 | 0.8 | 1.35 | tsci tessellated model, nominal
D2 | -15.75 | -2.19 | top | 4.6 | 0.95 | 3.85 | 1.7 | 0.8 | 2.25 | tsci tessellated model, nominal
D3 | -15.738 | 0.19 | top | 4.6 | 0.95 | 3.851 | 1.7 | 0.8 | 2.25 | tsci tessellated model, nominal
D4 | -15.9 | 2.57 | top | 4.6 | 0.95 | 3.85 | 1.7 | 0.8 | 2.25 | tsci tessellated model, nominal
J1 | 26.41 | 36.26 | top | 6.221 | 9.74 | 7.555 | 8.94 | -0.2 | 3.97 | GCT manufacturer OBJ, nominal
J2 | 0 | -32.34 | top | 17.191 | 5.026 | 16.1 | 6.4 | 0.8 | 2.9 | tsci tessellated model, nominal
J4 | -22.35 | -18.5 | top | 16.65 | 14.65 | 15.96 | 13.85 | 0.8 | 2.69 | tsci tessellated model, nominal
JP1 | -20.531 | 18.286 | top | 2.3 | 1.5 |  |  |  |  | PCB footprint only; no 3D body model
L1 | -22.377 | 0.203 | top | 4.22 | 6.124 | 5.0 | 5.02 | 0.8 | 2.91 | tsci tessellated model, nominal
L2 | 18 | 7 | top | 5.464 | 1.9 | 4.6 | 4.2 | 0.8 | 2.8 | tsci tessellated model, nominal
Q1 | -23.274 | 31.646 | top | 2.5 | 3.8 | 2.9 | 2.812 | 0.8 | 2.449 | tsci tessellated model, nominal
Q2 | -18.81 | -5.56 | top | 2.1 | 2.5 | 2.0 | 2.1 | 0.8 | 1.975 | tsci tessellated model, nominal
R1 | 12 | -32 | top | 0.95 | 2.45 | 0.85 | 1.6 | 0.8 | 1.4 | tsci tessellated model, nominal
R10 | -25.542 | 17.07 | top | 2.45 | 0.95 | 1.599 | 0.85 | 0.8 | 1.4 | tsci tessellated model, nominal
R11 | 19 | -26 | top | 0.95 | 2.45 | 0.85 | 1.6 | 0.8 | 1.4 | tsci tessellated model, nominal
R12 | 19.257 | 27.63 | top | 2.45 | 0.95 | 1.599 | 0.85 | 0.8 | 1.4 | tsci tessellated model, nominal
R13 | 19.24 | 26.03 | top | 2.45 | 0.95 | 1.6 | 0.85 | 0.8 | 1.4 | tsci tessellated model, nominal
R14 | -18.296 | 35.608 | top | 0.95 | 2.45 | 0.85 | 1.6 | 0.8 | 1.4 | tsci tessellated model, nominal
R15 | -19.871 | 35.608 | top | 0.95 | 2.45 | 0.85 | 1.6 | 0.8 | 1.4 | tsci tessellated model, nominal
R16 | -18.507 | -9.41 | top | 2.45 | 0.95 | 1.599 | 0.85 | 0.8 | 1.4 | tsci tessellated model, nominal
R17 | -15.68 | -8.02 | top | 1.4 | 2.85 | 1.25 | 2.0 | 0.8 | 1.35 | tsci tessellated model, nominal
R18 | 3.71 | -1.27 | top | 0.95 | 2.45 | 0.85 | 1.6 | 0.8 | 1.4 | tsci tessellated model, nominal
R19 | 6.89 | -1.27 | top | 0.95 | 2.45 | 0.85 | 1.6 | 0.8 | 1.4 | tsci tessellated model, nominal
R20 | -11.7 | -25.91 | top | 2.45 | 0.95 | 1.6 | 0.85 | 0.8 | 1.4 | tsci tessellated model, nominal
R21 | 5.27 | -1.27 | top | 0.95 | 2.45 | 0.85 | 1.6 | 0.8 | 1.4 | tsci tessellated model, nominal
R23 | 15 | -26 | top | 2.45 | 0.95 | 1.6 | 0.85 | 0.8 | 1.4 | tsci tessellated model, nominal
R24 | -11.7 | -24.386 | top | 2.45 | 0.95 | 1.6 | 0.85 | 0.8 | 1.4 | tsci tessellated model, nominal
R25 | 15 | -28 | top | 2.45 | 0.95 | 1.6 | 0.85 | 0.8 | 1.4 | tsci tessellated model, nominal
R27 | -11.15 | 31.77 | top | 2.45 | 0.95 | 1.6 | 0.85 | 0.8 | 1.4 | tsci tessellated model, nominal
R28 | 9.475 | 25.63 | top | 0.95 | 2.45 | 0.85 | 1.6 | 0.8 | 1.4 | tsci tessellated model, nominal
R29 | 21.5 | 14.1 | top | 2.45 | 0.95 | 1.6 | 0.85 | 0.8 | 1.4 | tsci tessellated model, nominal
R3 | 15 | -32 | top | 0.95 | 2.45 | 0.85 | 1.6 | 0.8 | 1.4 | tsci tessellated model, nominal
R30 | -11.15 | 29.5 | top | 0.95 | 2.45 | 0.85 | 1.6 | 0.8 | 1.4 | tsci tessellated model, nominal
R31 | 9 | 17 | top | 0.95 | 2.45 | 0.85 | 1.6 | 0.8 | 1.4 | tsci tessellated model, nominal
R32 | 9 | 14 | top | 0.95 | 2.45 | 0.85 | 1.6 | 0.8 | 1.4 | tsci tessellated model, nominal
R4 | -11.16 | 36.14 | top | 2.45 | 0.95 | 1.6 | 0.85 | 0.8 | 1.4 | tsci tessellated model, nominal
R5 | -28.92 | 30.39 | top | 2.45 | 0.95 | 1.6 | 0.85 | 0.8 | 1.4 | tsci tessellated model, nominal
R6 | 28 | -27 | top | 0.95 | 2.45 | 0.85 | 1.6 | 0.8 | 1.4 | tsci tessellated model, nominal
R7 | 19.282 | 29.86 | top | 2.45 | 0.95 | 1.599 | 0.85 | 0.8 | 1.4 | tsci tessellated model, nominal
R8 | 19.282 | 31.54 | top | 2.45 | 0.95 | 1.599 | 0.85 | 0.8 | 1.4 | tsci tessellated model, nominal
R9 | 8 | 21 | top | 0.95 | 2.45 | 0.85 | 1.6 | 0.8 | 1.4 | tsci tessellated model, nominal
S1 | -29.125 | -31 | top | 2.6 | 5.0 | 3.55 | 4.7 | 0.3 | 2.15 | tsci tessellated model, nominal
S2 | -29.075 | 23.08 | top | 2.6 | 5.0 | 3.55 | 4.7 | 0.3 | 2.15 | tsci tessellated model, nominal
SW2 | 7.0 | -42.5 | bottom | 5.25 | 2.85 | 4.698 | 3.2 | -3.31 | -0.8 | tsci tessellated model, nominal
SW3 | -7.0 | -42.5 | bottom | 5.25 | 2.85 | 4.698 | 3.2 | -3.31 | -0.8 | tsci tessellated model, nominal
SW4 | 21.0 | -42.5 | bottom | 5.25 | 2.85 | 4.698 | 3.2 | -3.31 | -0.8 | tsci tessellated model, nominal
SW6 | -21.0 | -42.5 | bottom | 5.25 | 2.85 | 4.698 | 3.2 | -3.31 | -0.8 | tsci tessellated model, nominal
SW7 | 26.85 | 14.105 | top | 4.5 | 7.8 | 7.53 | 9.0 | 0.0 | 4.35 | tsci tessellated model, nominal
TP1 | -12.5 | 43.432 | top | 1.5 | 1.5 |  |  |  |  | PCB footprint only; no 3D body model
TP2 | -3.361 | 18.692 | top | 1.5 | 1.5 |  |  |  |  | PCB footprint only; no 3D body model
TP3 | 15 | 44 | top | 1.5 | 1.5 |  |  |  |  | PCB footprint only; no 3D body model
TP4 | -9.711 | 8.43 | top | 1.5 | 1.5 |  |  |  |  | PCB footprint only; no 3D body model
TP5 | -12.962 | 8.481 | top | 1.5 | 1.5 |  |  |  |  | PCB footprint only; no 3D body model
TP6 | 19.042 | 22.146 | top | 1.5 | 1.5 |  |  |  |  | PCB footprint only; no 3D body model
U1 | 13 | 17 | top | 3.85 | 3.85 | 3.02 | 3.02 | 0.8 | 1.56 | tsci tessellated model, nominal
U2 | 19.92 | 36.407 | top | 3.37 | 2.432 | 2.812 | 2.9 | 0.8 | 2.449 | tsci tessellated model, nominal
U3 | -23.249 | 36.624 | top | 3.37 | 2.432 | 2.813 | 2.9 | 0.8 | 2.449 | tsci tessellated model, nominal
U4 | 0.25 | 34.78 | top | 19.3 | 12.9 | 18.0 | 14.3 | 0.8 | 4.01 | tsci tessellated model, nominal
U5 | 11 | 7 | top | 4.4 | 3.6 | 4.02 | 3.02 | 0.8 | 1.81 | tsci tessellated model, nominal

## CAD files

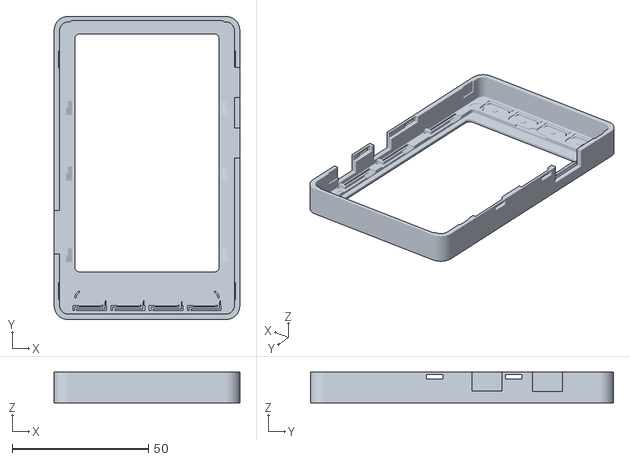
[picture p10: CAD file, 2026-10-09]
assets/enclosure/print/front-chassis.stl
68.0 x 111.0 x 11.2

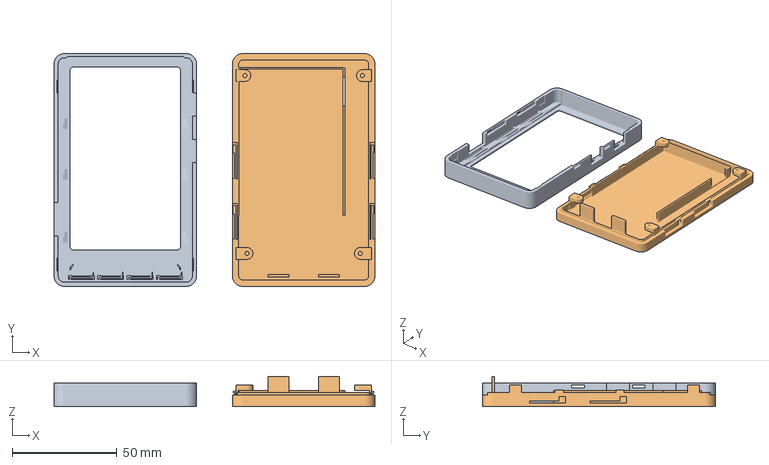
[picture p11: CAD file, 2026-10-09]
assets/enclosure/reader-print-plate.3mf
153.0 x 111.0 x 14.4 mm
front-chassis
rear-cover

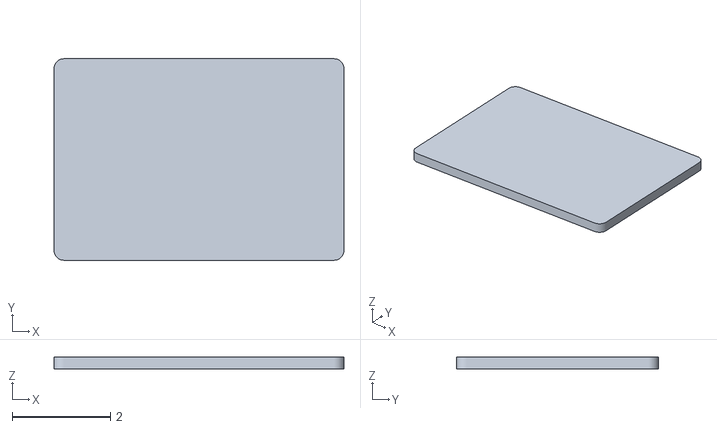
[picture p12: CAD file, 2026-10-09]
assets/enclosure/stl/antenna-envelope-DO-NOT-PRINT.stl
5.90 x 4.10 x 0.24

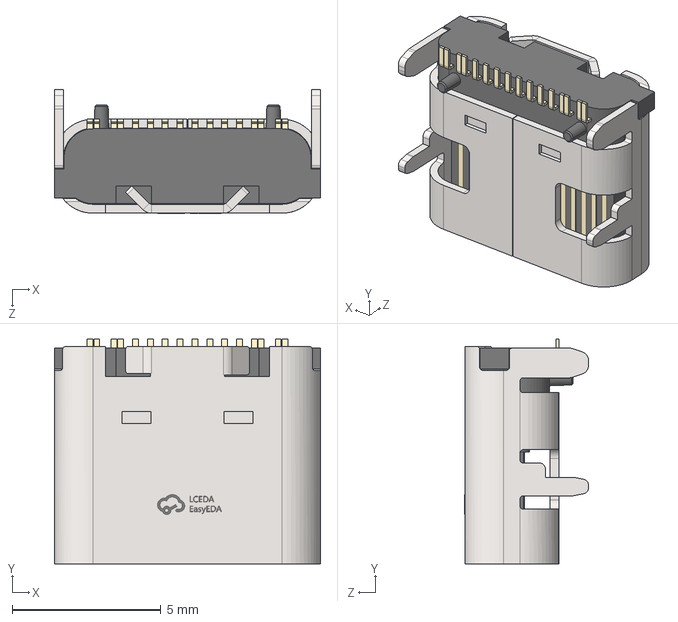
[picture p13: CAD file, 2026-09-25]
imports/USB4105_GF_A/USB4105_GF_A.step
8.94 x 7.55 x 4.17 mm

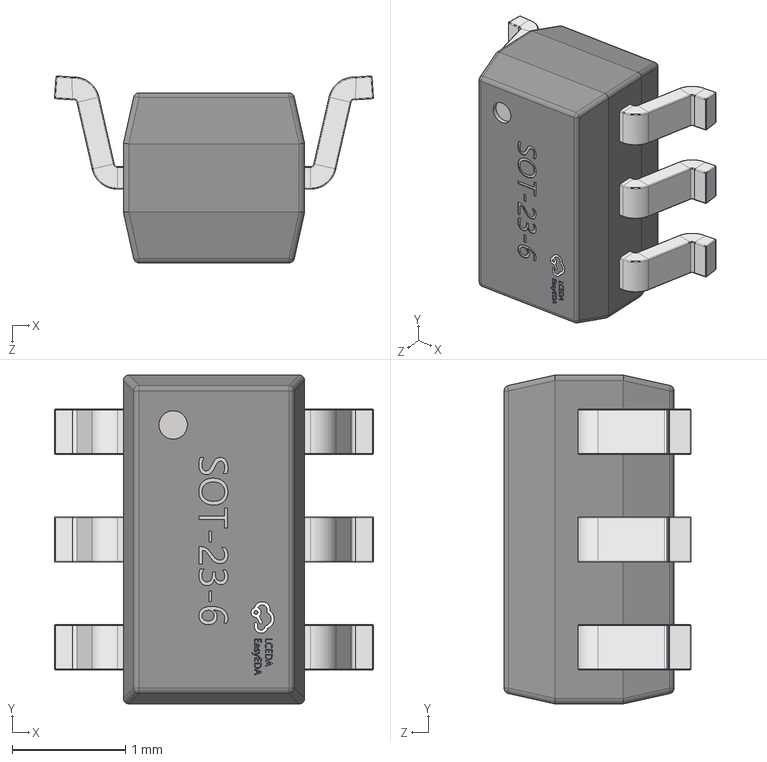
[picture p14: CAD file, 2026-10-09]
assets/components/C7519.step
2.81 x 2.90 x 1.65 mm

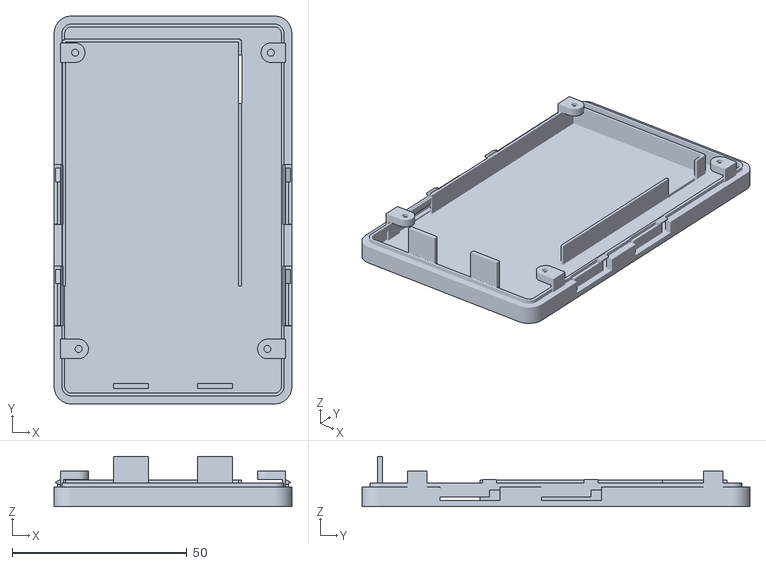
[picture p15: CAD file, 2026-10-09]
assets/enclosure/print/rear-cover.stl
68.0 x 111.0 x 14.4

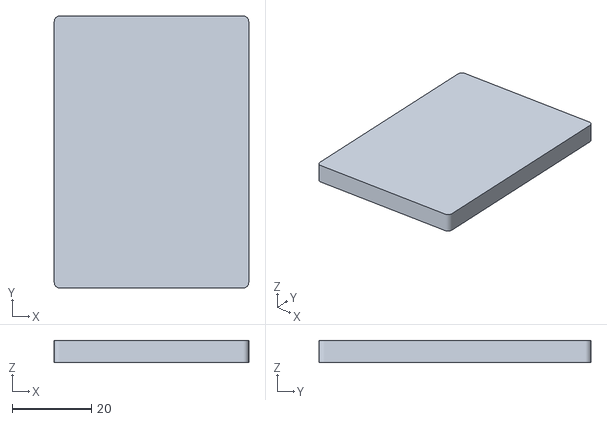
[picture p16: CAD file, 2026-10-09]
assets/enclosure/stl/battery-envelope-DO-NOT-PRINT.stl
49.2 x 68.8 x 5.60

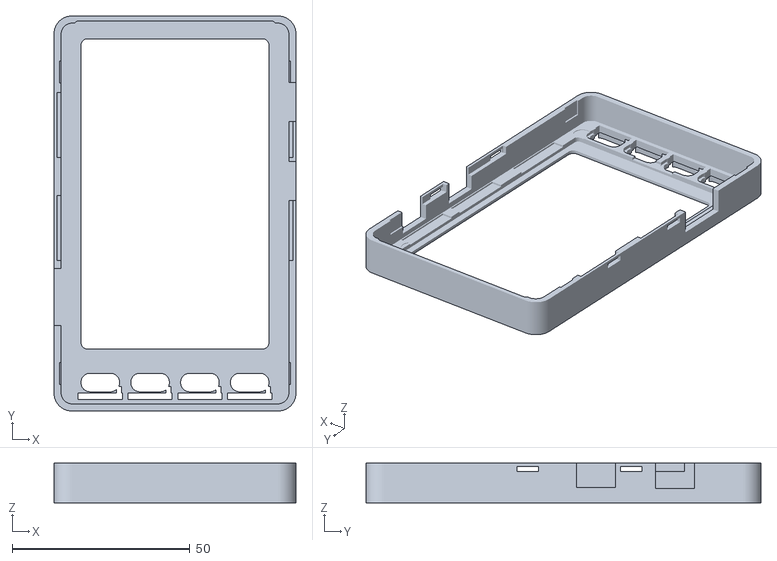
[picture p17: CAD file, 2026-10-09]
assets/enclosure/stl/front-rigid-DO-NOT-PRINT.stl
68.0 x 111.0 x 11.2

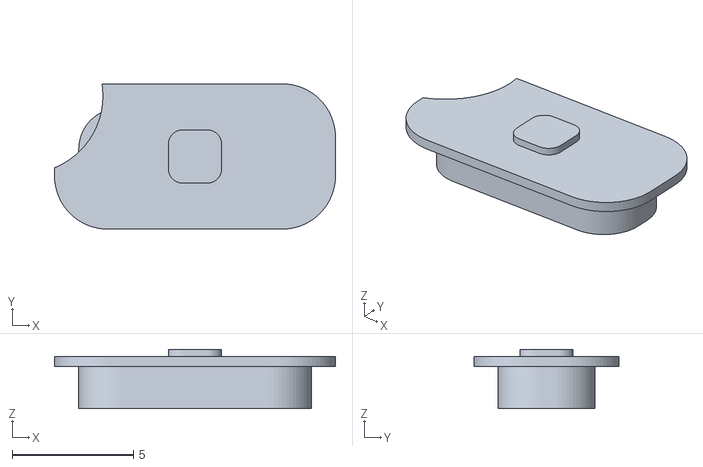
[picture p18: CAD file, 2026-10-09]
assets/enclosure/stl/button-1-DO-NOT-PRINT.stl
11.6 x 6.00 x 2.45

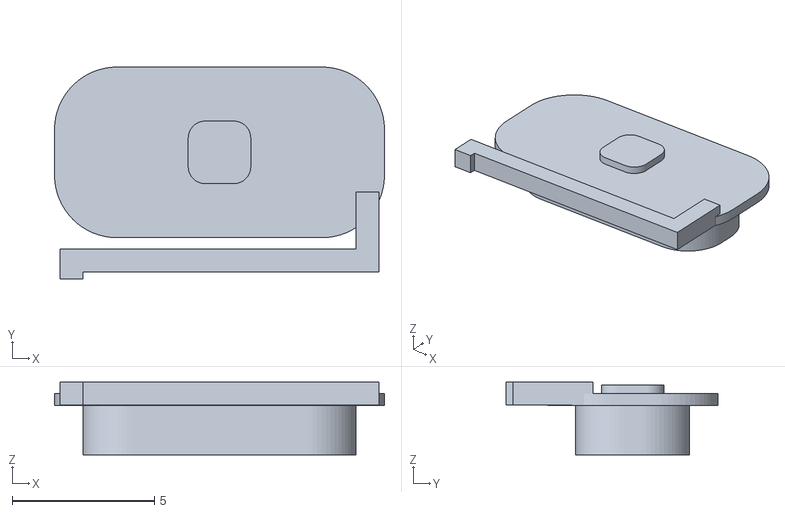
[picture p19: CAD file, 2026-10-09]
assets/enclosure/stl/button-moving-3-DO-NOT-PRINT.stl
11.6 x 7.45 x 2.55

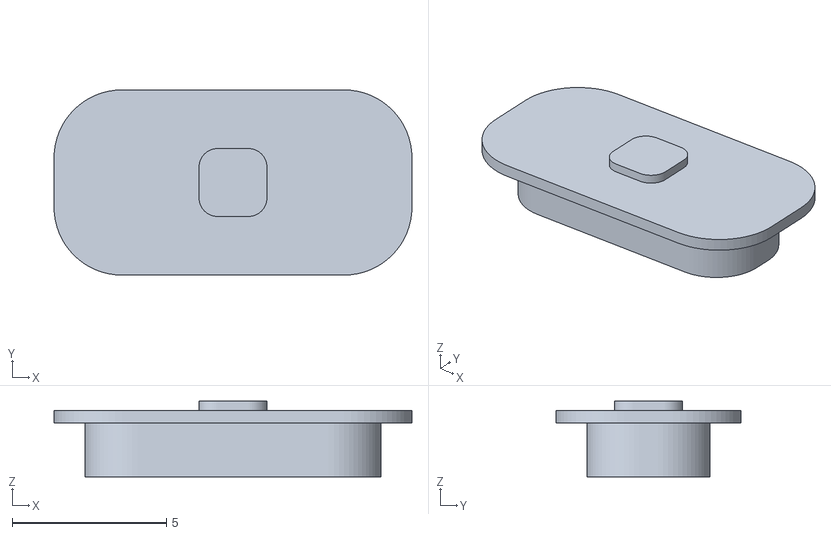
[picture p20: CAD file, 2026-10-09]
assets/enclosure/stl/button-2-DO-NOT-PRINT.stl
11.6 x 6.00 x 2.45

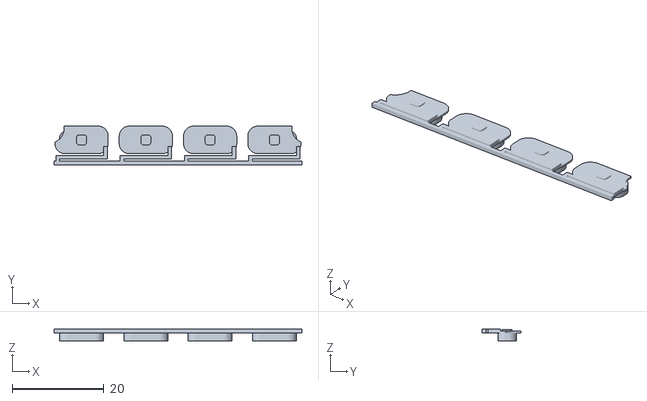
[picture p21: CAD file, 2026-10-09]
assets/enclosure/stl/button-flexures-DO-NOT-PRINT.stl
54.0 x 8.45 x 2.55

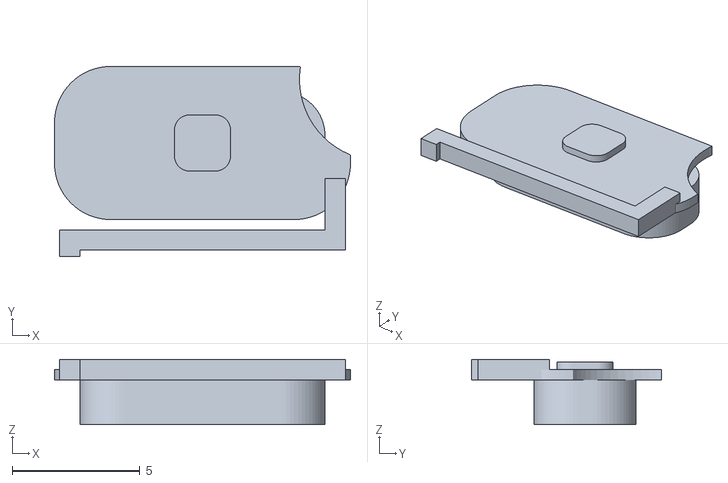
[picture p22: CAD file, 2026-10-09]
assets/enclosure/stl/button-moving-4-DO-NOT-PRINT.stl
11.6 x 7.45 x 2.55

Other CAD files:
assets/enclosure/stl/rear-rigid-DO-NOT-PRINT.stl
assets/enclosure/stl/button-3-DO-NOT-PRINT.stl
assets/enclosure/stl/button-moving-2-DO-NOT-PRINT.stl
assets/enclosure/stl/button-4-DO-NOT-PRINT.stl
assets/enclosure/stl/button-moving-1-DO-NOT-PRINT.stl
assets/components/C114218.obj
assets/components/C114218.step
assets/components/C133190.obj
assets/components/C133190.step
assets/components/C139797.obj
assets/components/C139797.step
assets/components/C173752.obj
assets/components/C173752.step
assets/components/C202112.obj
assets/components/C202112.step
assets/components/C202140.obj
assets/components/C202140.step
assets/components/C221660.obj
assets/components/C221660.step
assets/components/C2830320.obj
assets/components/C2926676.obj
assets/components/C2926676.step
assets/components/C2927799.obj
assets/components/C388883.obj
assets/components/C388883.step
assets/components/C469327.obj
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

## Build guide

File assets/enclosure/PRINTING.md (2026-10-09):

# Rev. E: two-piece, 16.8 mm snap-fit enclosure

Print **two parts**: `front-chassis` and `rear-cover`. The front chassis includes
all four navigation keys, their independent PETG spring leaves and
six releasable screen clips and four cover latch receivers. The rear cover includes
PCB cantilever bosses, four integral cover snap tabs, battery guides and two
supports for the upper display border. There is no printed tray,
separate bezel, button strip or loose display-retaining frame.

The nominal outside envelope is **68 × 111 × 16.8 mm**, 1.2 mm thinner than
Rev. D's 18.0 mm (6.7%), and reduced from Rev. C's 21.1 mm. The battery is
shifted toward the button end to clear the ESP32 module, allowing the rear
cover to move 1.2 mm closer to the PCB. The screen support, navigation keys,
PCB, component placement and electrical connections are unchanged.
Four side snap tabs replace the cover screws. Print both Rev. E shells together;
the front receivers and rear hooks form a matched pair.
The same protected pack is centered at X −6.0, Y −8.5 mm and attaches to the
rear cover with two nonconductive adhesive strips. The 0.2 mm insulating liner,
0.5 mm adhesive and 1.2 mm rear wall are retained.

Download [the print ZIP](esp32-reader-printable-stls.zip) or import the
[220 × 220 mm 3MF plate](reader-print-plate.3mf). It contains exactly two separate
objects, already oriented, in millimetres at 100% scale. Select your actual
printer and PETG preset. The ZIP also contains the two oriented STLs, this guide
and the geometry specifications and validation reports. No printer-specific G-code is supplied.
Files under `stl/` retain PCB coordinates for inspection. Files marked
`DO-NOT-PRINT` represent gauges, the battery, film or purchased supplies.

## Printing

Working setup: FDM with a 0.4 mm nozzle, PETG, 0.2 mm layers, three walls,
five top/bottom layers and 20% gyroid infill. PETG is required for the integral
key leaves, cover snap tabs and releasable display clips. Both shells print with their flat
outside face on the bed; no enclosure tilting or scaling is required.

Use removable snug supports, including supports that start on the part, at a
45° threshold with a 0.2 mm contact gap. The reference profile enables supports
under bridges. Inspect the six screen leaves, four button leaves, four cover
snap leaves, PCB screw features and seam tongue in the slicer. All those regions are accessible while
the shells are empty. Carefully remove support without cutting the spring
leaves. The battery pocket is open, so no support is trapped in a closed cavity.
Use your printer's calibrated temperature, cooling and speed settings. Follow
its plate instructions for PETG release layers and add a brim if required.

[fdm-reference.ini](fdm-reference.ini) records geometry-check settings; it is not
a calibrated machine preset. Prusa's guides describe [printing tolerances and
orientation](https://help.prusa3d.com/article/modeling-with-3d-printing-in-mind_164135)
and [support placement](https://help.prusa3d.com/article/support-material_1698).
The reference PrusaSlicer 2.9.6 plate uses about **32.2 g of PETG**, including
**1.5 g of support**, with an estimated **3 h 49 min** on the reference profile.
The exact results are recorded in [printability-check.json](stl/printability-check.json).
Actual printer speed and material settings change those estimates. A successful
slice verifies generated toolpaths. Fit, switch force, clip release force and
printed fatigue still require a physical prototype.

## Transparent cover

The actual front and rear GLBs use alpha blending: the smoke-tinted front has
0.38 opacity, and the rear has 0.22 opacity. The hosted tscircuit view and native
export apply 0.5 opacity through the explicit translucency flag on both shells.
These views show the electronics through the enclosure. That visual opacity does not
predict an actual print's optical clarity.

Clear PETG may be used for both parts. Normal FDM layers produce a translucent
cover; it will not look like glass. Keep the PETG flexures if printing the front
in another color. Resin would require separate flexibility and tolerance
validation; the included geometry and slicing checks assume PETG FDM.

## Required nonprinted supplies

- Four M2.5 × 4 mm PCB screws, head diameter ≤5 mm and head height ≤2.5 mm.
  The board clamps against the rear-cover boss underside at Z +0.8. Screws
  enter from the display-facing side, with heads at Z −3.3…−0.8 and tips at
  Z 3.2. Prepare the nominal 2.0 mm pilots before fitting electronics.
- Display-compatible nonconductive cushioning: ten front border pads,
  installed thickness 0.15 mm; six small rear clip pads and two upper support
  pads, installed thickness 0.35 mm. Never place a hard clip on bare glass.
  Locations are recorded in the generator and [enclosure-design.json](enclosure-design.json).
- A 49.4 × 69 × 0.2 mm nonconductive PET or suitable equivalent liner, including
  its thin adhesive, on the PCB-facing battery surface. It is an insulating
  sheet, not a printed part. Keep edges away from connector contacts.
- Two pouch-compatible, nonconductive foam adhesive strips, nominally
  10 × 50 × 0.5 mm, to attach the battery's rear face to the inside cover.
  Use an adhesive suitable for your actual protected pack and PETG. The guides
  locate the pack; adhesive retention must be tested on the real materials.

The case uses **four internal PCB screws**, with **zero cover screws**. Hardware envelopes
are nominal; head shapes, threads, tolerances and printer shrinkage need testing.

## Assembly

1. Print, remove supports, clear/tap PCB screw pilots and inspect both empty shells.
   Dry-fit the cover and release all four tabs through the side windows with
   a plastic pick. The nominal inward release movement is 0.6 mm. Check that
   each tab springs back and its hook engages before installing electronics.
   Check all four integral keys for independent movement and return. Their
   nominal 0.25 mm key stroke includes a 0.04 mm rest gap and about 0.21 mm switch
   compression. A worn key requires replacing the front chassis, which is the
   tradeoff for eliminating separate printed buttons.
2. Fit the ten thin front pads to the screen ledge. Attach the six small pads to
   the undersides of the side clip lips and the two pads to the rear cover's
   upper screen supports. Spread the six side leaf tips outward using plastic
   picks, keeping force on the clips rather than the display. The CAD release
   check uses 1.0 mm lateral tip movement. Lower the panel straight into its
   rebate, then release the clips gently. They bear only on the padded border.
   Stop if the panel cannot seat or any clip presses its active area.
3. With the PCB removed, dry-fit the battery loading path. Enter through the
   open upper end of the guides with the pack centered at X −6.0, Y −2.0.
   Lift it toward the lid, leaving 0.1 mm stand-off, then slide it 6.5 mm toward
   the lower stop to Y −8.5. This passes above the lower PCB mounting bosses.
   Apply the insulating liner to the PCB-facing pack surface and use the two
   adhesive strips with accessible release pull tabs. Leave their release film
   in place while locating the pack; peel and bond once it is in position.
   Verify the real adhesive, release-film thickness and pull-tab access during
   the dry fit. Do not squeeze or bend the pouch to complete the loading path.
   The nominal 49.2 × 68.8 × 5.6 mm protected pack is centered at X −6.0,
   Y −8.5; its PCB-facing surface is Z 3.7. Guides allow 0.2 mm nominal edge
   clearance. Verify the complete pack envelope, labels, lead and adhesive fit.
4. Attach the antenna film near X 25, Y 44 on the rear cover. Seat the PCB
   straight into the rear cover from its open display-facing side, against the
   four cantilever bosses at Z +0.8. Fit the four M2.5 × 4 screws from the
   PCB underside. This leaves access to the pilots and avoids posts crossing
   the glass insertion path.
5. Bring the two loaded halves together without tension on the display tail.
   Feed the panel tail through the PCB slot. Open J2's latch, insert the tail
   with contacts toward the PCB, then close it. J2 remains the selected 24-pin,
   0.5 mm Hirose connector. Confirm the delivered panel's pin 1, contact side,
   stiffener and permitted fold radius; the installed ribbon model is nominal.
   Connect the battery to BT1: pin 1 `BATT_P` is near X 21.05, pin 2
   `BATT_N_RAW` near X 23.05. Confirm actual keyed plug polarity. Route the
   battery lead through the guide notch and antenna coax to U4 without trapping
   either. Real cable slack and installation access need a physical sample.
6. Lower the loaded rear cover and attached PCB straight onto the front chassis.
   Its two upper support columns pass beyond the PCB and cushion the top
   screen border. Align the seam, then press at each latch location until all
   four hooks engage. The tongue sets alignment and the perimeter seam sets
   closure depth. Do not force a lid over a trapped wire or pack.

To open the cover, press the recessed hooks inward through the four side
windows with a plastic pick. Keep the first pair released while releasing the
other pair, then lift the loaded rear cover straight. Avoid twisting the screen
or pulling on the ribbon.

For screen service, disconnect the display tail and remove the loaded rear cover, then release the six screen clips. No loose retaining frame needs dismantling.

## Geometry and validation

The PCB origin is retained: screen/front is negative Z, battery/rear positive Z.

| Feature | Nominal dimensions / position |
| --- | --- |
| Outside | 68 × 111 × 16.8; X ±34, Y −50.5…60.5, Z −5.8…11.0; radius 5 |
| Front display ledge | Floor Z −4.8, 1.0 mm minimum front material; ten 0.15 mm pads |
| Panel / visible window | 56.24 × 96.62 × 0.9 / 52.8 × 87.2; center Y 10.5 |
| Screen pocket | 56.8 × 97.2; 0.28/0.29 mm nominal edge clearance |
| Side clips | Six; tip Y −27, 3, 27; 14 mm spring leaves; padded face Z −3.4 |
| Upper rear supports | X ±12, Y 55.4; padded face Z −3.4, beyond the PCB outline |
| PCB | 62.5 × 95.08 × 1.6; Z ±0.8; four original mount positions |
| Shell seam | Z 5.4; 0.2 mm side tongue clearance and 0.3 mm end clearance |
| Rear outside face | Z 11.0; 1.2 mm flat cover, with four integral snap leaves |
| Battery stack | 0.2 mm liner at Z 3.5…3.7; cell at 3.7…9.3; 0.5 mm adhesive to Z 9.8 |
| Guides | 0.8 mm; side X −31.2/19.2; lower stop Y −43.5; upper loading end open |
| Cover snaps | Four; sides X ±32.6, tip Y −5/24; 14 mm beams, 0.8 mm thick |
| Snap engagement / release | 0.4 mm radial engagement; 0.2 mm vertical play; 0.6 mm inward release |
| Snap receivers | 0.8 mm retaining walls; accessible 6 × 1.5 mm side windows |
| USB/SD/switch access | Front-wall openings reach the seam to clear the attached PCB at closure |

The lower PCB mounting bosses set this revision's height limit. The liner
has 0.25 mm nominal clearance above their Z 3.25 tops and about 0.59 mm above
L1, the tallest electronic body under the shifted battery. Its edge is 1.63 mm
below the ESP32 module in Y. During loading, the 0.1 mm lid stand-off leaves
0.15 mm nominal clearance over the lower bosses.
The same battery capacity and insulation are retained. Confirm the actual pack
thickness and clearance on a prototype, including any swelling allowance;
do not force closure onto the pack. Actual battery cables, antenna coax,
printed shrinkage, adhesive strength and flexure fatigue are not simulated.
The snap checks verify hook retention, geometric release, and sampled closing
and opening paths. They do not predict snap force or cycle life.

Regenerate and verify using:

```sh
blender --background --python-exit-code 1 --python scripts/generate-printable-enclosure.py
bun run build
bun run export:assembly
blender --background --python-exit-code 1 --python scripts/check-enclosure-clearance.py -- dist/index/assembly.glb
blender --background --python-exit-code 1 --python scripts/check-display-connection.py -- dist/index/assembly.glb
python3 scripts/check-printability.py /path/to/prusa-slicer
blender --background --python-exit-code 1 --python scripts/render-printable-enclosure.py
```

Generated reports under `stl/` record mesh integrity, nominal clearances,
independent key strokes, sampled screen/PCB/battery/cover assembly paths,
CAD transparency and slicer output. The source still contains the original
supplier STEP models; the hosted STEP archives ([1](../components/supplier-step-models-1.zip), [2](../components/supplier-step-models-2.zip), [3](../components/supplier-step-models-3.zip), [4](../components/supplier-step-models-4.zip), [5](../components/supplier-step-models-5.zip))
preserve them without loading large STEP duplicates in the browser preview.

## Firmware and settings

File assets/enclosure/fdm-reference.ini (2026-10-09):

# Geometry validation profile, not a printer-specific G-code profile.
# Select your printer and its PETG filament preset before printing.
bed_shape = 0x0,220x0,220x220,0x220
max_print_height = 250
nozzle_diameter = 0.4
filament_diameter = 1.75
filament_type = PETG
filament_density = 1.27
layer_height = 0.2
first_layer_height = 0.2
perimeters = 3
top_solid_layers = 5
bottom_solid_layers = 5
fill_density = 20%
fill_pattern = gyroid
perimeter_generator = arachne
support_material = 1
support_material_auto = 1
support_material_style = snug
support_material_threshold = 45
support_material_contact_distance = 0.2
support_material_interface_layers = 3
support_material_buildplate_only = 0
dont_support_bridges = 0
brim_width = 0
threads = 2

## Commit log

2026-09-03 Use tscircuit autorouter for PCB routing
2026-09-03 Refactor design-data.ts to simplify footprint references and update capacitor footprint usage; adjust FH12 model rotation offset to 0; enhance autorouter configuration in index.circuit.tsx.
2026-09-08 Update USB-C declaration, LED footprint, and board snapshots
2026-09-10 Fix manufacturing footprints and four-layer layout
2026-09-23 Center display FPC slot for extension cable
2026-09-23 Reduce assembly cost for quad-color display
2026-09-23 Add hardware main power switch
2026-09-25 Use larger navigation switches and fix routing
2026-09-25 Add enclosure mounting and USB-C model
    [USB4105_GF_A.obj, USB4105_GF_A.step]
2026-09-29 Add schematic sheets and update tscircuit to 0.0.2663
2026-09-30 Update tscircuit and verify routed e-reader board
2026-10-01 Compact e-reader controls and enclosure
2026-10-02 Add slim printable enclosure and complete hardware guide
    [battery-envelope-DO-NOT-PRINT.stl, battery-partition.stl, button-1.stl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]
2026-10-02 Show rear enclosure cover in 3D assembly
2026-10-03 Prepare ESP32 E-Reader Rev B prototype release
    [antenna-envelope-DO-NOT-PRINT.stl, component-envelopes.csv, component-inventory.csv]
2026-10-03 Show reference designators on custom schematic symbols
2026-10-03 Fix U2 schematic symbol rendering
2026-10-05 Center display connector and use standard JLCPCB via sizes
2026-10-07 Use configured supplier part for charge status LED
2026-10-07 Improve all schematic sheets and preserve verified PCB routing
2026-10-07 Fix control switch schematic terminals and connect ADC ladder
2026-10-07 Add lower PCB mounts and enclosure screw access
    [battery-partition.stl, button-1.stl, button-4.stl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]
2026-10-08 Model folded e-paper ribbon and align display connector
    [component-envelopes.csv, component-inventory.csv, front-shell.stl]
2026-10-08 Add removable padded display retaining frame
    [display-retainer-lower-left.stl, display-retainer-lower-right.stl, display-retainer-upper-left.stl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]
2026-10-09 Simplify enclosure to five printable parts and bundle CAD models
    [C114218.obj, C114218.step, C133190.obj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]
2026-10-09 Clarify the one-piece navigation button strip
2026-10-09 Redesign enclosure as two transparent printable shells
    [antenna-envelope-DO-NOT-PRINT.stl, battery-envelope-DO-NOT-PRINT.stl, battery-partition.stl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]
2026-10-09 Split supplier CAD downloads to meet registry upload limits
2026-10-09 Recreate printable archives for Git-linked builds
    [reader-print-plate.3mf]
2026-10-09 Enable translucent enclosure shells in hosted 3D viewer
2026-10-09 Restore enclosure preview images in Git-linked builds
2026-10-09 Reduce enclosure thickness and add releasable snap-fit cover
    [antenna-envelope-DO-NOT-PRINT.stl, battery-envelope-DO-NOT-PRINT.stl, front-chassis.stl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]
2026-10-11 Replace power switch with C431541 and verify enclosure fit
2026-10-11 Adapt Waveshare display and protect ribbon between navigation buttons
    Use the Waveshare 3.97-inch (G) panel geometry and offset FH34SRJ connector,
    with exact supplier footprints and CAD. Route its tail around the PCB edge
    through a protected channel between the two navigation-button pairs.
    Update the two-part enclosure, mounts, installation paths, printable meshes,
    previews and reference slice reports. Preserve verified routing and discard
    disconnected solver seeds only when a complete replacement is present.
    Validate TypeScript, netlist and placement, all four copper layers, mounting
    keepouts, assembly export, native CAD clearance and packaged print assets.
    Document the remaining physical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
2026-10-12 Replace short-stock parts and model the battery harness
    Use C165948 USB-C and C15220 BQ24073 with supplier footprints, remapped USB contacts and grounded TD. Update validated routing, assembly guards and CAD previews, including the protected battery and its wired connection. Prepare release 1.0.81.
2026-10-12 Restore CAD and print assets in Git-linked release builds
    Preserve missing STL/GLB assets in lossless compressed text backups with checksum verification. Omit duplicated preview binaries from registry inputs and use compressed tsci uploads. Isolated runtime build and all asset hashes pass. Prepare release 1.0.83.
2026-10-15 Preserve diode polarity markings with exact supplier footprints
